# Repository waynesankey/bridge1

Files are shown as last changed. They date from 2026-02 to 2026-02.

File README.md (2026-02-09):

This is a PCB design for a UART to WiFi bridge that goes with the bridge1_sw repo software.

The bridge has a Raspberry Pi Pico 2W microcontroller and runs AI generated MicroPython code.

The bridge is used to provide a web browser interface to remotely control a preamp.  The UART
connects to a microcontroller in the preamp that controls the local display, inputection relays,
mute relay, volume control chips, etc.

The bridge is housed in an inexpensive plastic box that need not be visible to the user and
is connected to the preamp by a 4-pin M12 A-coded umbilical cable.  The cable has female ends, while the
bridge and preamp both have 4-pin M12 A-coded male ends.

The signal chain is:

iPhone <-> WiFi <-> BRIDGE1 (Raspberry Pi Pico 2W) <-> UART (4-pin M12 cable) <-> Preamp (Raspberry Pi Pico)

And the iPhone controls and GUI show the state of the Preamp which holds the true state of the
system - so eg. if the volume decoder on the Preamp is used to adjust the volume, that change is
immediately seen on the iPhone GUI.

W. Sankey
2/9/26

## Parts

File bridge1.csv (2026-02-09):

Reference | Qty | Value | Footprint | Datasheet
C1 | 1 | 220uF | Wayne:EEE1AA221P | ~
C2 | 1 | 100uF | Wayne:16SVF180M | ~
C3,C4 | 2 | 1.0uF | Capacitor_SMD:C_1206_3216Metric | ~
C5 | 1 | 0.1uF | Capacitor_SMD:C_1206_3216Metric | ~
D1 | 1 | SS14 | Diode_SMD:D_SMA | ~
FB1 | 1 | BLM41 | Inductor_SMD:L_1806_4516Metric | ~
J1 | 1 | 1935187 | Wayne:1935187 | http://www.phoenixcontact.com/us/products/1935187/pdf
R1 | 1 | 150 | Resistor_SMD:R_0603_1608Metric | ~
U1 | 1 | pico | Module:RaspberryPi_Pico_Common_Unspecified

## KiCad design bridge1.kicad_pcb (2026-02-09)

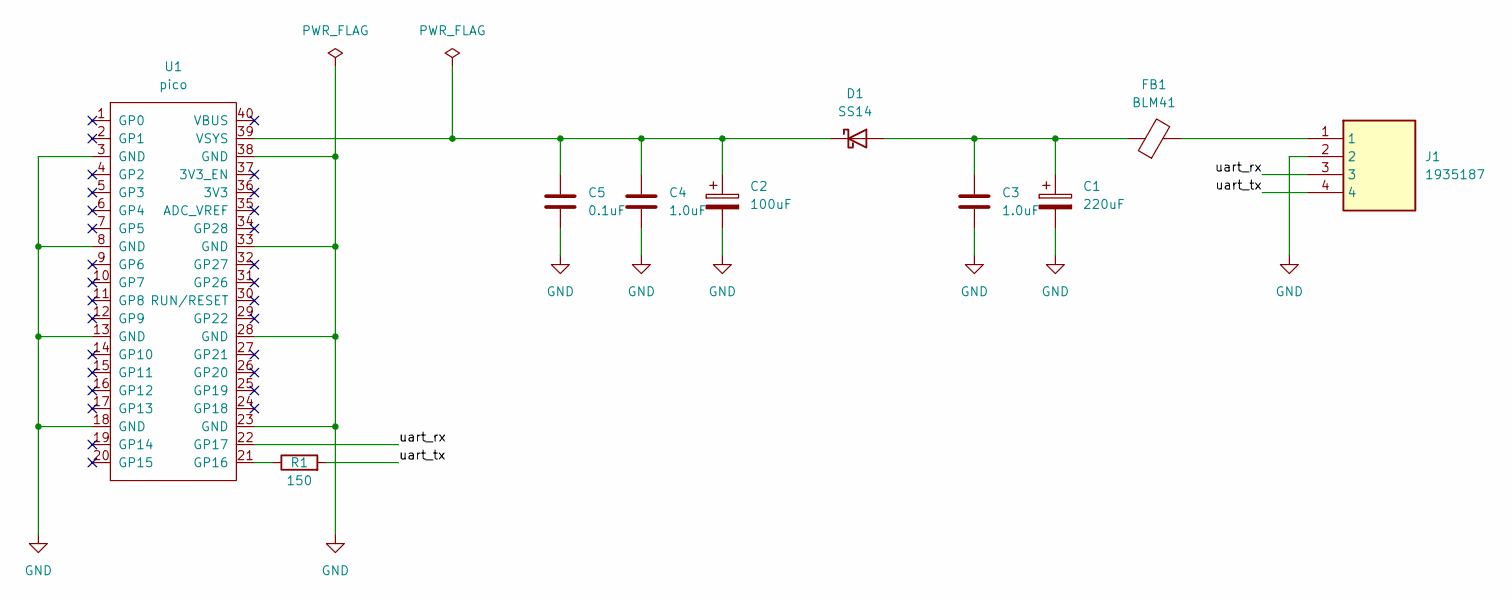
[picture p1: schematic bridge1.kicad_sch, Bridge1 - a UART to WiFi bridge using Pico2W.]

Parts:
C1: 220uF; EEE1AA221P
C2: 100uF; 16SVF180M
C3, C4: 1.0uF; C_1206_3216Metric
C5: 0.1uF; C_1206_3216Metric
D1: SS14; D_SMA
FB1: BLM41; L_1806_4516Metric
J1: 1935187; Mouser Part Number 651-1935187
R1: 150; R_0603_1608Metric
U1: pico; RaspberryPi_Pico_Common_Unspecified

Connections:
/uart_rx: J1.3, U1.22 (GP17)
/uart_tx: J1.4, R1.2
GND: C1.2, C2.2, C3.2, C4.2, C5.2, J1.2, U1.3 (GND), U1.8 (GND), U1.13 (GND), U1.18 (GND), U1.23 (GND), U1.28 (GND), U1.33 (GND), U1.38 (GND)
unnamed: C1.1, C3.1, D1.2 (A), FB1.1
unnamed: C2.1, C4.1, C5.1, D1.1 (K), U1.39 (VSYS)
unnamed: FB1.2, J1.1
unnamed: R1.1, U1.21 (GP16)

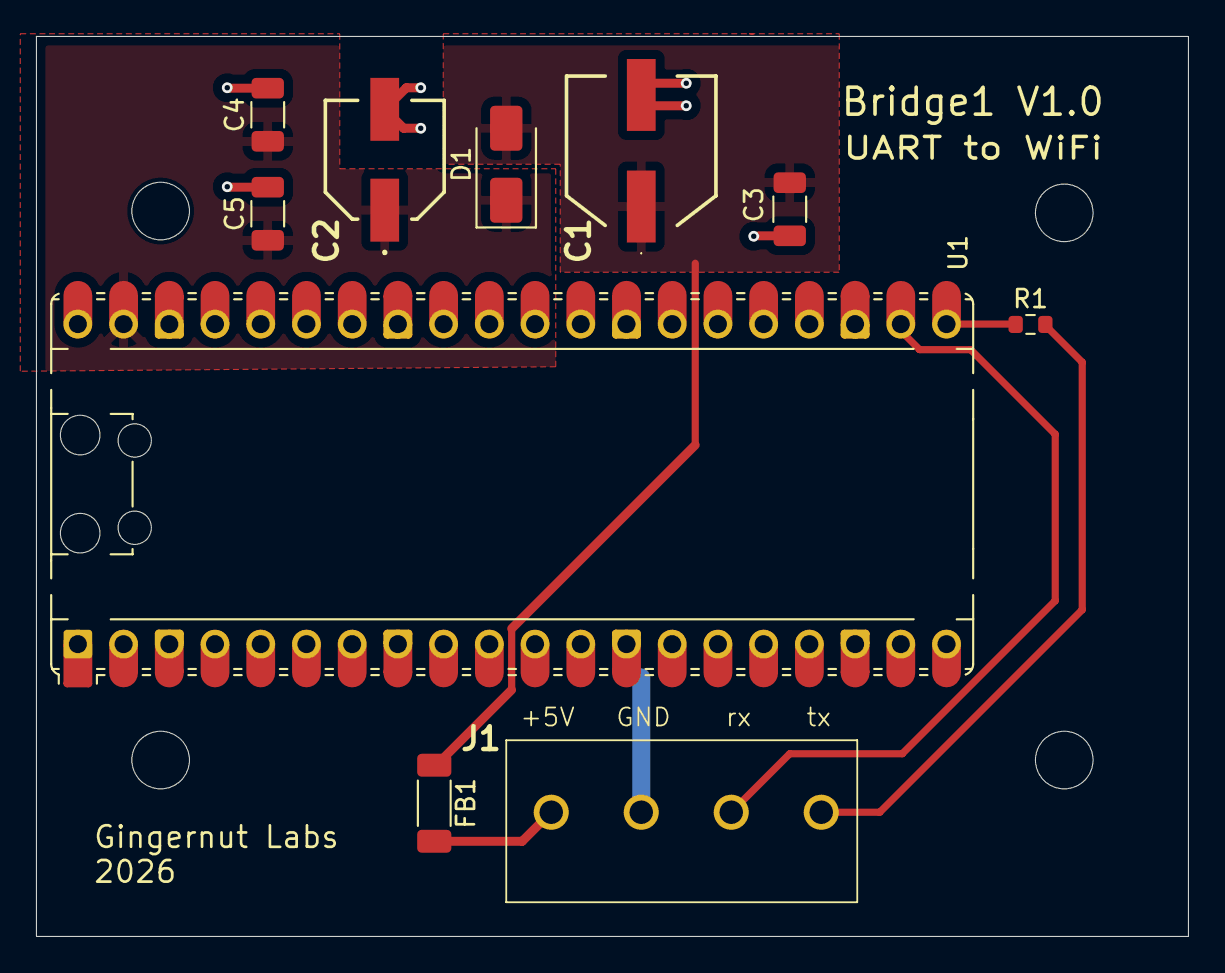
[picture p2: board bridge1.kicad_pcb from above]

Board: 2 copper layers, 64.0 x 50.0 mm, 10 parts (0 on the bottom side), 7 nets.

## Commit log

2026-02-06 Add KiCad .gitignore
2026-02-06 Initial schematic design for bridge
    [bridge1.kicad_sch]
2026-02-07 Updated schematic and project files with full design
    [bridge1.kicad_sch]
2026-02-07 Updated schematic to fix duplicated annotations on copied GND symbols, no functional change. ERC passes on this commit.
    [bridge1.kicad_sch]
2026-02-08 Updated schematic and PCB files with JLCPCB parts and PCB design underway
    [bridge1.kicad_pcb, bridge1.kicad_sch]
2026-02-08 Updated schematic and PCB files, have full layout now.
    [bridge1.kicad_pcb, bridge1.kicad_sch]
2026-02-08 Updated PCB file to remove ground plane under pico 2W for RF transmission
    [bridge1.kicad_pcb]
2026-02-08 Updated schematic and PCB files to change R1 to 0603 package, J1 to green screw terminal block.
    [bridge1.kicad_pcb, bridge1.kicad_sch]
2026-02-08 Updated PCB file to optimize layout a bit, add silkscreen text.
    [bridge1.kicad_pcb]
2026-02-09 Updated PCB file to properly place mounting holes.
    [bridge1.kicad_pcb]
2026-02-09 Updated PCB file to widen the UART tracks to 0.4mm from 0.2mm
    [bridge1.kicad_pcb]
2026-02-09 added BoM bridge1.csv
    [bridge1.csv]
2026-02-09 updated project and pcb files post-ordering V1 PCBs - added 3D models to C1 and C2. No change to design.
    [bridge1.kicad_pcb]
